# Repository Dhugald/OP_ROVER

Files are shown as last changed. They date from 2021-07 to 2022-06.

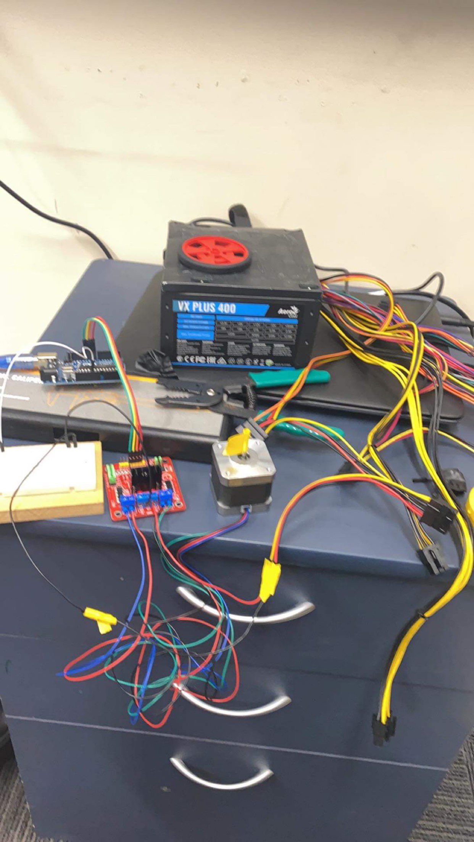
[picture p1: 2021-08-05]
Photos/StepperTest.jpg

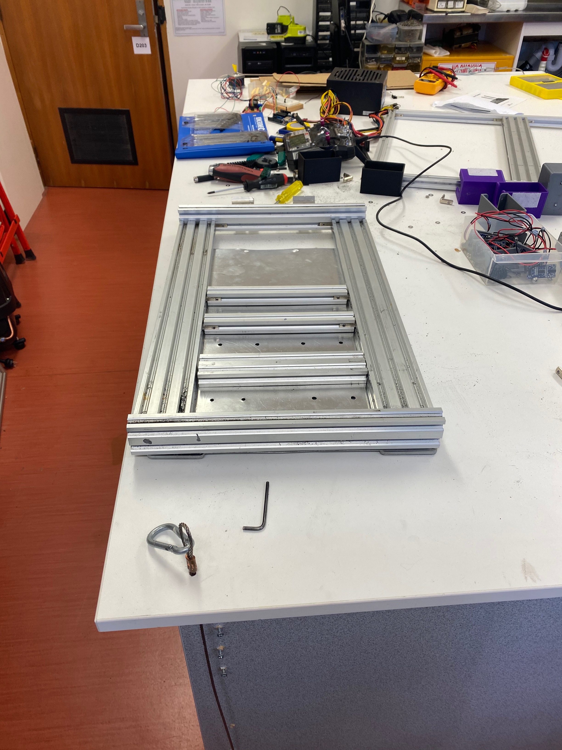
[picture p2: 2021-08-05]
Photos/Base.png

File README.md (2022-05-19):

# Rover Project

## This is the main github for the Rover project.
The purpose of this project is to create a self driving all terrain surverying robot, Used for checking out areas that could be unsafe for people to get to.

We want to be able to have it get over and around hazardous areas autonomously and map out areas using a lidar to show any risks and areas of concern.

# Members
- Reuben Watt
- Taylor Medder
- Dhugald Spry

# Plan
## Base plan

Rover has a 540mm x 320mm base.
Need to trim off the sides of the existing frame, maybe create a smaller box frame for the internal components?

## Wheels and legs planning
750mm length for the rocker-bogie when set-up, need to calculate the total length of parts
150mm diameter wheels (Similar to the ones used to farmbot(killbot) if possible to find).

Might need to make a 3d model of the base and the legs to get a better feel of them.

## Sensor layout
- Lidar to make a minimap to find entrys and exits.
- Lidar to spin and map a room in 3d on unity
- Camera to view through
- Sensors on all 4 sides to help with obstacle avoidance and detection

As a group we need to work out a sensor layout that we all agree on.

# Research links

Nvidia Jetson? Possible replacement for the Raspberry Pi, Could be cool to try
https://www.nvidia.com/en-us/autonomous-machines/jetson-store/

ROS with Lidar
https://www.generationrobots.com/blog/en/lidar-integration-with-ros-quickstart-guide-and-projects-ideas/
https://www.daslhub.org/unlv/wiki/doku.php?id=using_ros_to_read_data_from_a_hokuyo_scanning_laser_rangefinder

ROS Tutorial:
http://wiki.ros.org/ROS/Tutorials

Information on stepper motors:
https://nz.rs-online.com/web/generalDisplay.html?id=ideas-and-advice/stepper-motors-guide

NASA software:
https://software.nasa.gov/

Open Source Scaled Down 6 wheeled rover:
https://github.com/nasa-jpl/open-source-rover

CAD Parts for it: 
https://github.com/nasa-jpl/open-source-rover/tree/master/mechanical/rocker_bogie

Lidar 3D scan:
https://www.youtube.com/watch?v=gCpCGkwwy8I&ab_channel=TechsOnTube

Curiosity Rover 3D model and part descriptions:
https://mars.nasa.gov/msl/rover-3d/

Some More Images for ideas on the differential bar and rocker bogie system:
https://beatty-robotics.com/curiosity-mars-rover/

Lidar object detection:
https://www.youtube.com/watch?v=_--8K1BW_O4&t=2s&ab_channel=GreatScott%21

Some More Lidar Info For 3d Scan
http://charleslabs.fr/en/project-3D+Lidar+Scanner

Stepper motors:
https://www.youtube.com/watch?v=bkqoKWP4Oy4&ab_channel=GreatScott%21
https://www.youtube.com/watch?v=fHAO7SW-SZI&ab_channel=iforce2d

ROS tutorial:
https://www.youtube.com/watch?v=9U6GDonGFHw&ab_channel=JustinHuang

ROS lectures:
7 videos total From what I've seen will be really helpful.
https://www.youtube.com/playlist?list=PLE-BQwvVGf8HOvwXPgtDfWoxd4Cc6ghiP

Using a lidar for robot nav:
https://www.youtube.com/watch?v=OJNNm6iMOKk&ab_channel=TheLinuxFoundation

# Similar Projects

Uses Ardupilot and ROS, Contains alot of information and ideas that we can use:
https://dronebotworkshop.com/6-wheel-rover-introduction/

6 Wheeled Mars rover design for terrain traversing, equipment servicing, astronaut assistance and on-board testing.
More detailed and hightech than what we are going for but still contains information that might be usefull:
https://www.researchgate.net/publication/313543991_6_Wheeled_Mars_rover_design_for_terrain_traversing_equipment_servicing_astronaut_assistance_and_on-board_testing

A replica of the Perseverance rover, includes code and other helpful hints in the guide:
https://www.youtube.com/watch?v=NOZZMsMAGh0&ab_channel=HowToMechatronics
https://howtomechatronics.com/projects/diy-mars-perseverance-rover-replica-with-arduino/

ROS rover project, might have some useful information on the OS:
https://github.com/danielsnider/ros-rover

Example of what ROS can do, Ardupilot used to set a path:
https://www.youtube.com/watch?v=tqVH4lWk51Y&ab_channel=RandyMackay

Really useful robot, uses ROS:
https://youtu.be/M9ABtlEM788

# 3D printed parts list

Wheels (Need to be edited for casting):

# Shopping List
(Possible Stepper Motors from JayCar https://www.jaycar.co.nz/arduino-compatible-5v-stepper-motor-with-controller/p/XC4458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 - Have a feeling these will be to small for the work load.)

Wheels, the same ones from farmbot:
https://shop.wheelco.co.nz/shop//Wheels/Rubber+Wheels/Zero+Pressure+Wheel+150mm+-+Offset+Hub+-+ZPM150B.html

Possible stepper motors, might change type of motors.
https://www.digikey.co.nz/product-detail/en/trinamic-motion-control-gmbh/QSH6018-56-28-165/1460-1082-ND/4843432
https://www.digikey.co.nz/product-detail/en/trinamic-motion-control-gmbh/QSH6018-56-28-165/1460-1082-ND/4843433

Coupler for wheel and wheel motor 
https://www.jaycar.co.nz/solid-shaft-couplers-female-type-ii/p/YG2602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

Slipring
https://core-electronics.com.au/slip-ring-with-flange-22mm-diameter-6-wires-max-240v-at-2a.html

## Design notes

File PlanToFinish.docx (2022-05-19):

Wiring diagrams

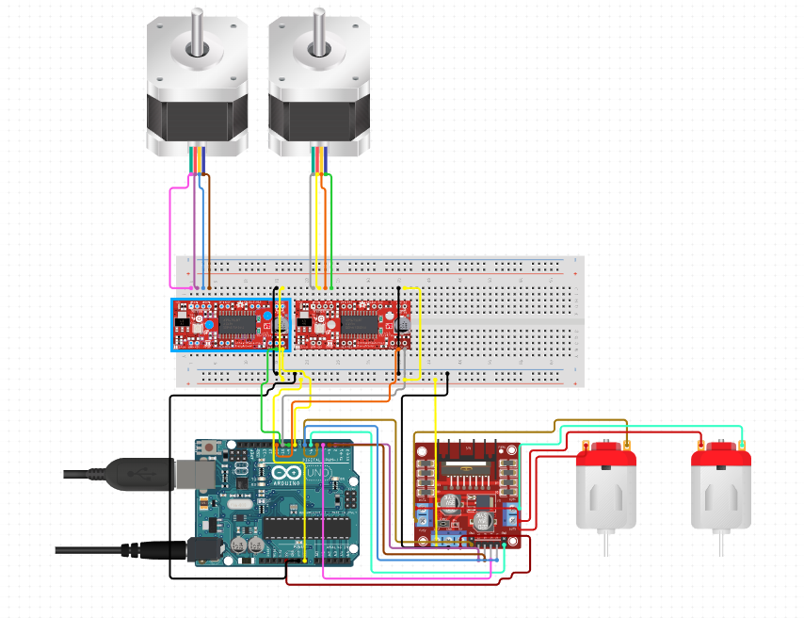
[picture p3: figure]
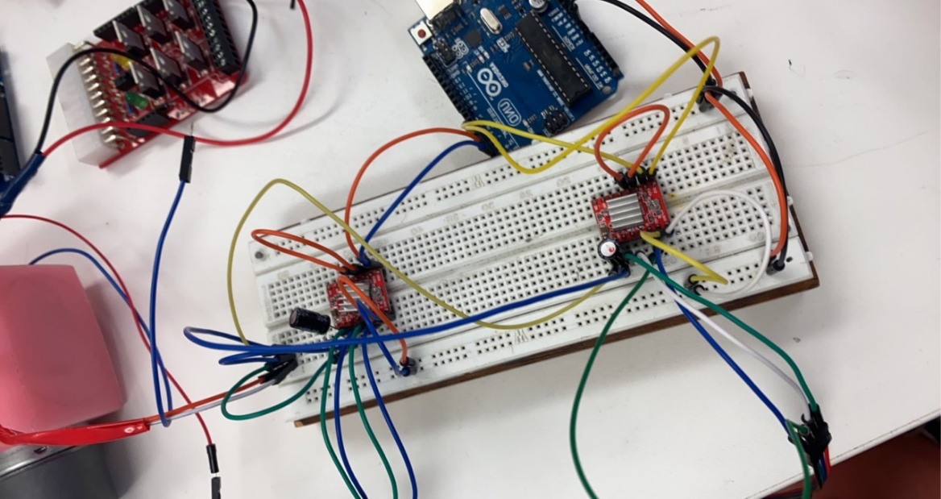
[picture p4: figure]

2x Slave board for the front and back motor set. Drivers are slightly different, but wiring is easy. External power for all the Arduinos and motor drivers from the PSU (hopefully) using the spark fun shield driver kit

Powering each Arduino using the 12v connector and the stepper drivers using the 5v

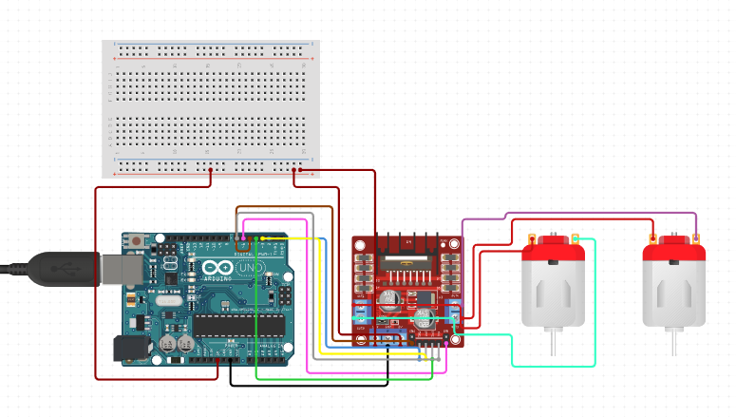
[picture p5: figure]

Slave board for the middle motors, very basic setup, can also use a TB6612FNG driver if it provides enough power to the motors.

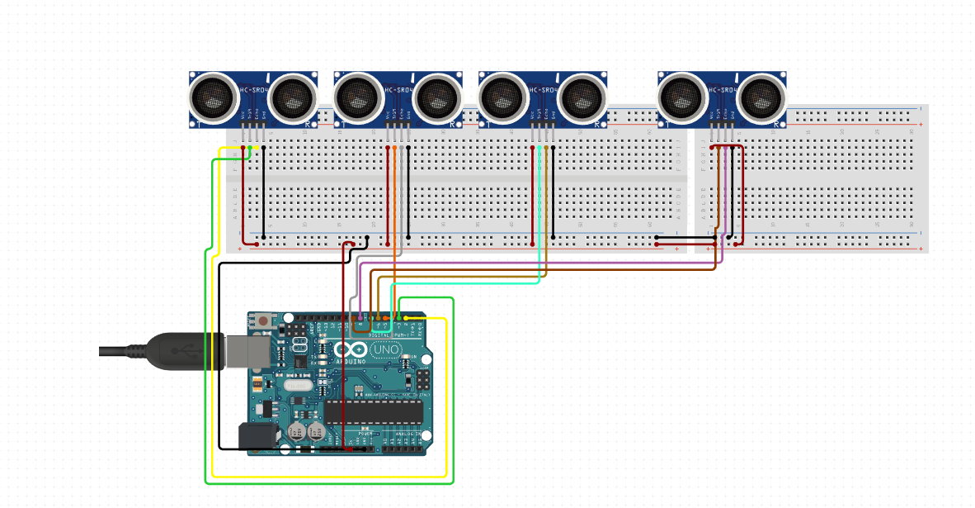
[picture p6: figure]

Master board includes the echo sensors to judge distances for decision making.

All the slave boards connect to the master board using i2c using the SDA and SCL ports on the uno (A4, A5)

The master board will be making the decisions based off the echo sensors then telling the slave boards the decision, Finite-state machine is probably the play for this.

All going the plan we will have a rover that can control itself and avoid obstacles.

Tasks that we need to complete.

- Mount the parts
  - Find bolts to connect our 3d prints to the rover.
  - Figure out most effective way to mount wheels to the DC motors.
- Wire up the motors
  - Either solder the parts or use breadboards
- Write code
  - Two slave boards will have the same code
  - Master board must do the decision making
  - Final slave board to power middle wheel motors
- Figure out the shield driver kit for the power distribution.
- Have fun doing it 😊 (optional)

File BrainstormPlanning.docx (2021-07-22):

Planning

1. 3D Mapping
  1. Detailed?
  2. Display dots in unity
2. 2D Mini-map
  1. Way pointing
3. Camera control
  1. Live feed
  2. Joystick
  3. Zoom in controls
  4. Capture live videos and photos
4. AI Risk evaluation
5. Wheel control
  1. 90° degree wheel rotation
  2. Rocker-bogie mechanism
6. Self Driving
  1. Sensor control
  2. Pathfinding
  3. Decision making
  4. Drive to waypoints from 2D map
7. Control buttons
  1. Start / stop
  2. Scan
  3. Photo?
  4. Video?

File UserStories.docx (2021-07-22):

User Stories

As a user I want to be able to remotely get a map of an area to spot potential areas of concern so that we aren’t putting people in possible harm’s way.

As a user I want to be able to see an area through the camera to spot risks in higher detail with control of the camera, so that we can have high detail photos and video of the potential risk area.

As a user I want the rover to safely navigate through areas of interest so that the rover doesn’t get any damage from the terrain.

As a creator I want to be able to build it in parts that will last, this will hopefully be done with help from the engineering students so that the parts are built to last and won’t have to be replaced as often.

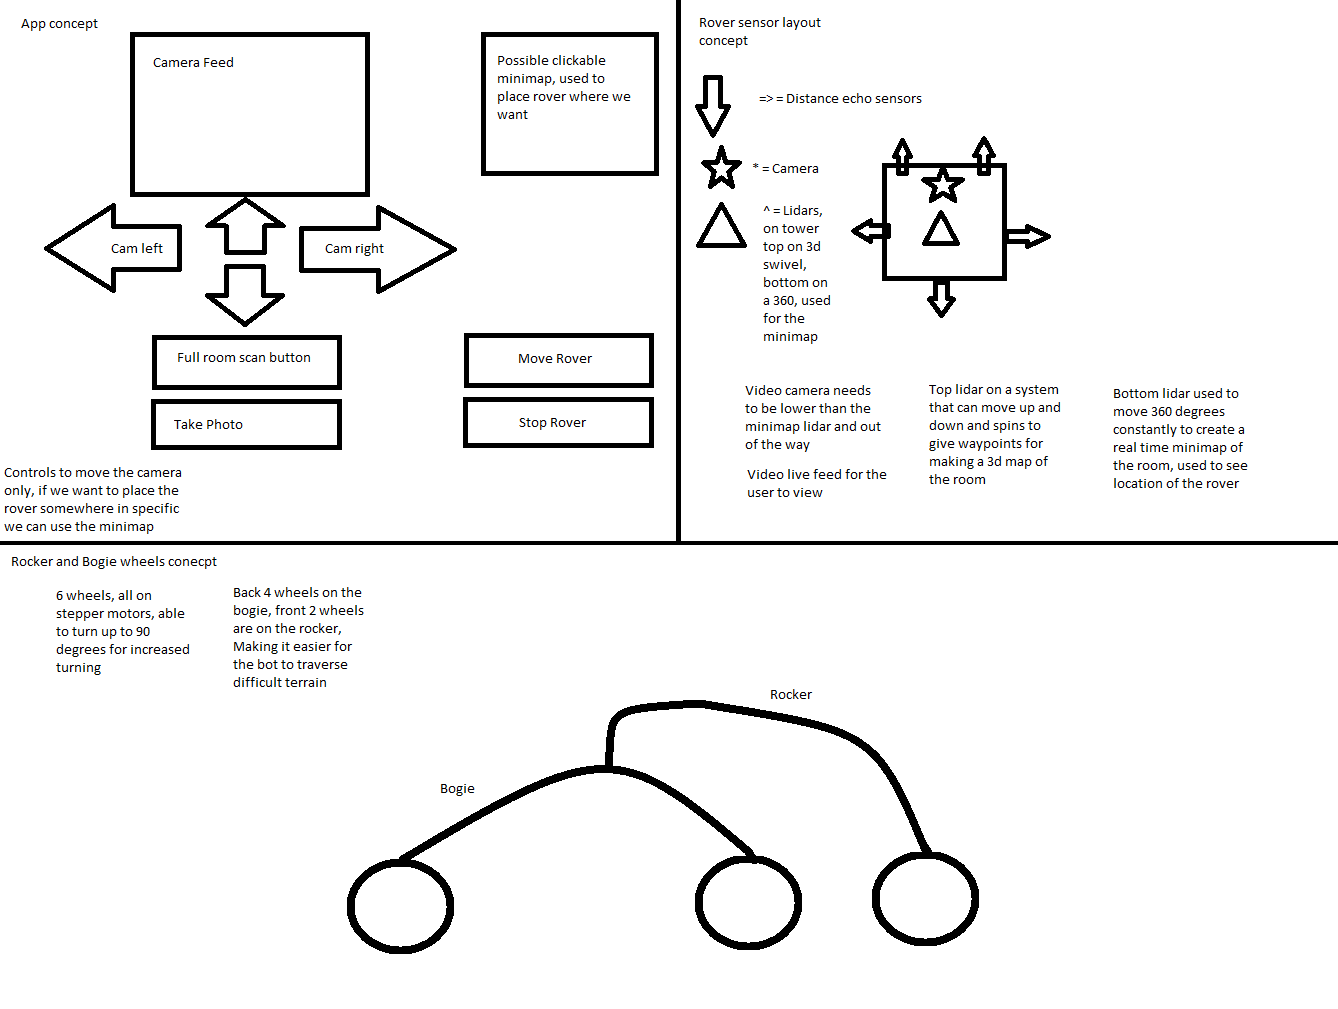
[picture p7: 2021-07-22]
Photos/Concepts.png

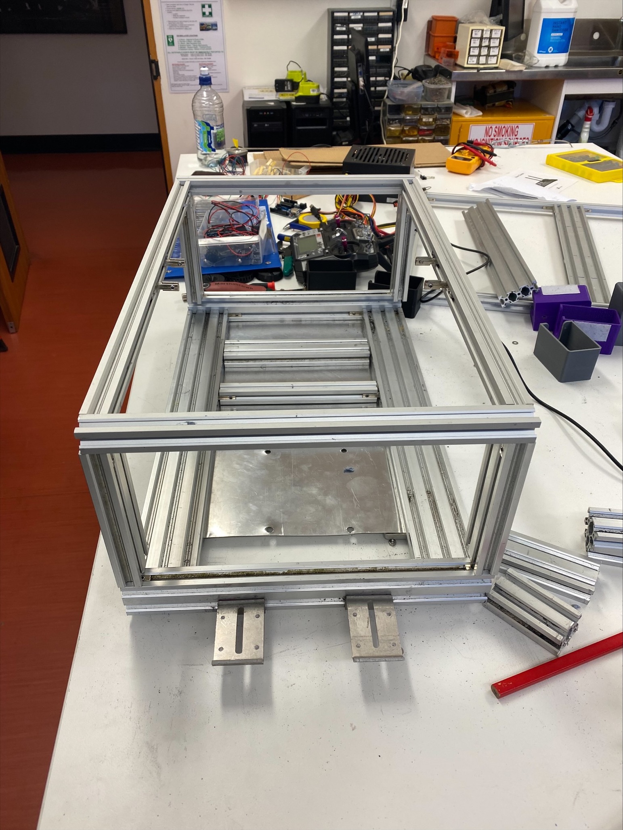
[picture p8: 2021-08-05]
Photos/Frame.png

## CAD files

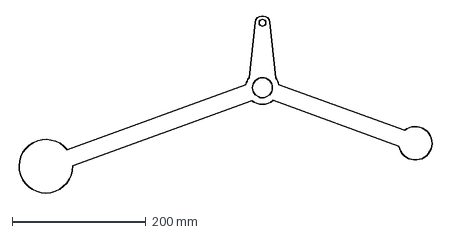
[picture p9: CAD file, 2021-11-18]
3D parts/DXF Files/Rocker.dxf
623.7 x 267.2 mm

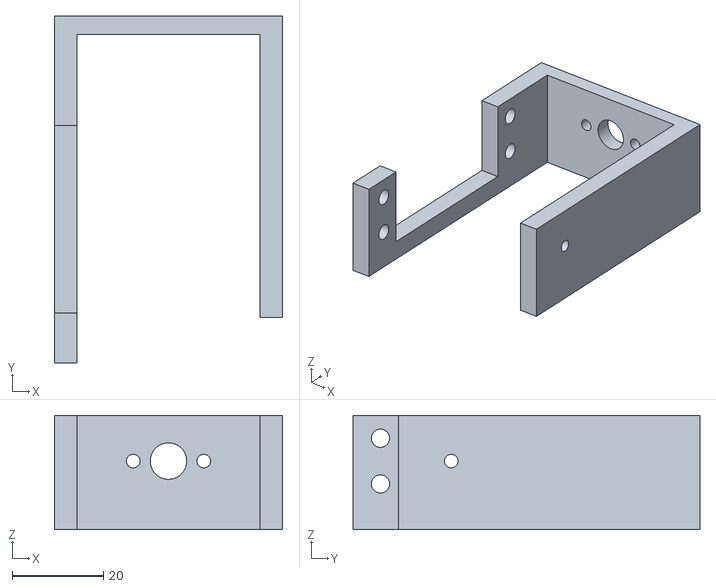
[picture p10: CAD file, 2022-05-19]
3D parts/Lidar Scanner Brackets/Redesigned LIDAR-Servo-Housing-Pocket.stl
50.0 x 76.0 x 25.0

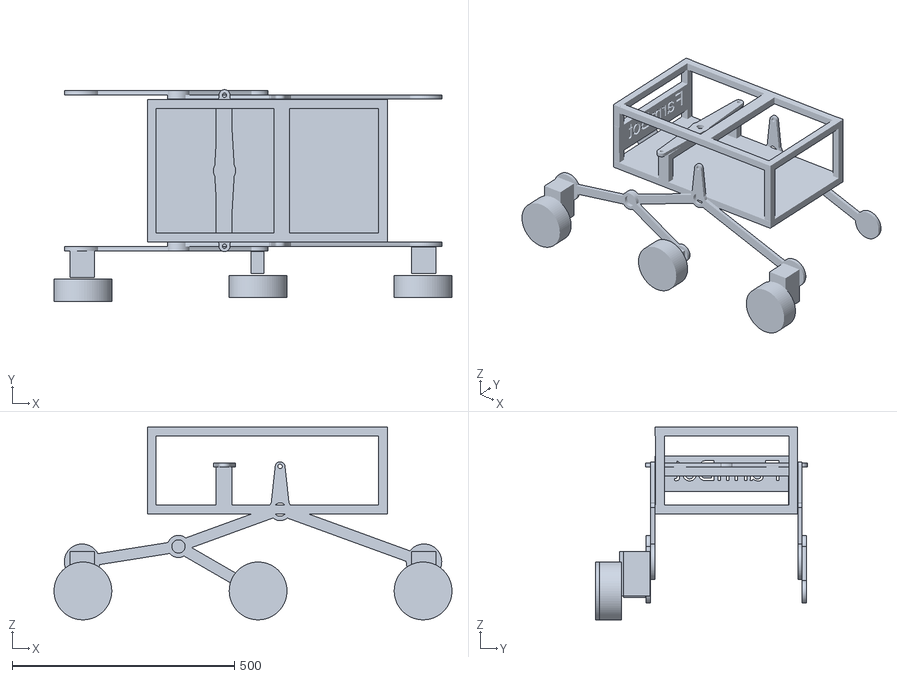
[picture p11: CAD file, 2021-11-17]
3D parts/Rover Bogie Rocker v14 (NEW).stl
895.0 x 476.1 x 433.1

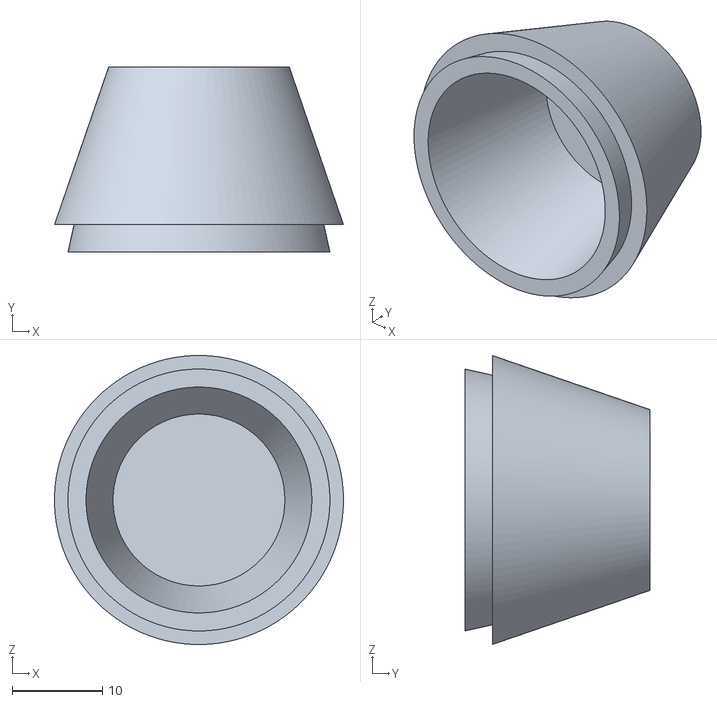
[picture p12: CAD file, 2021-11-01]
3D parts/Wheel/hub cap v1.stl
32.0 x 20.5 x 32.0

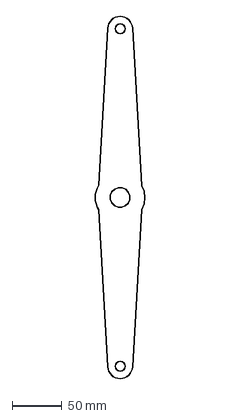
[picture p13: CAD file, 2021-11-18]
3D parts/DXF Files/Differential Bar.dxf
52.1 x 364.6 mm

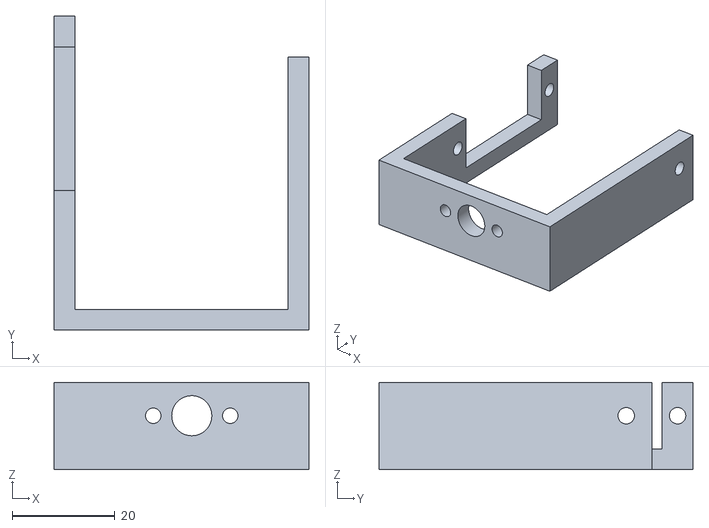
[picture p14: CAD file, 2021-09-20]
3D parts/Lidar Scanner Brackets/LIDAR-Servo-Housing-Pocket002.stl
49.6 x 61.1 x 17.0

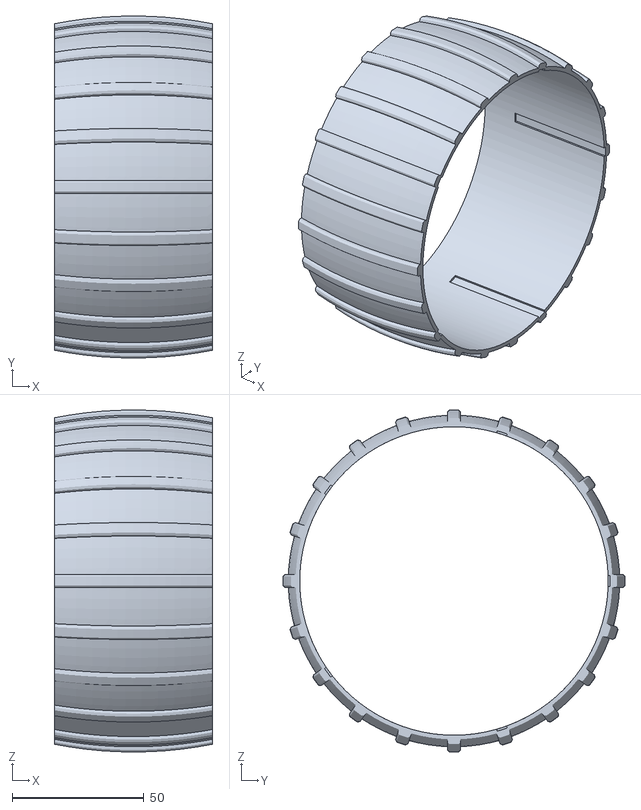
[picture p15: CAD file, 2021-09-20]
3D parts/Wheel/wheel_rim_2.stl
60.0 x 129.6 x 129.6

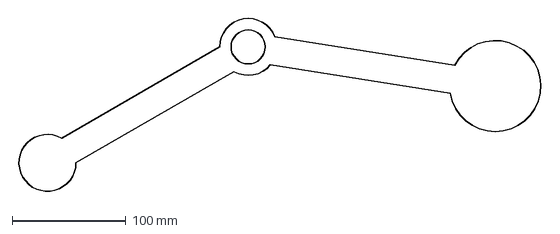
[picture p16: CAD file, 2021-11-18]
3D parts/DXF Files/Bogie.dxf
463.1 x 155.7 mm

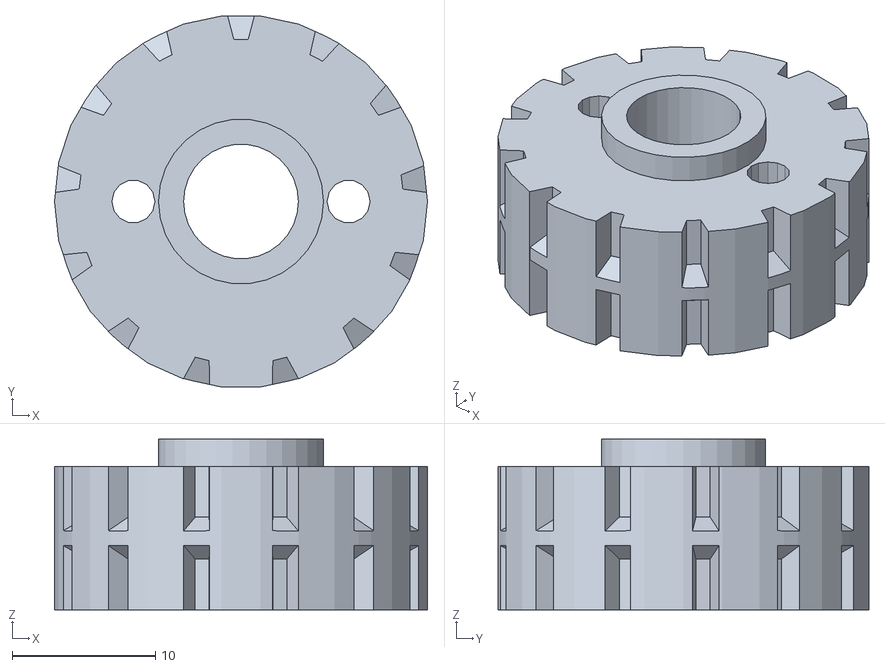
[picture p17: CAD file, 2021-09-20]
3D parts/Lidar Scanner Brackets/Slipring.stl
26.0 x 25.9 x 11.9

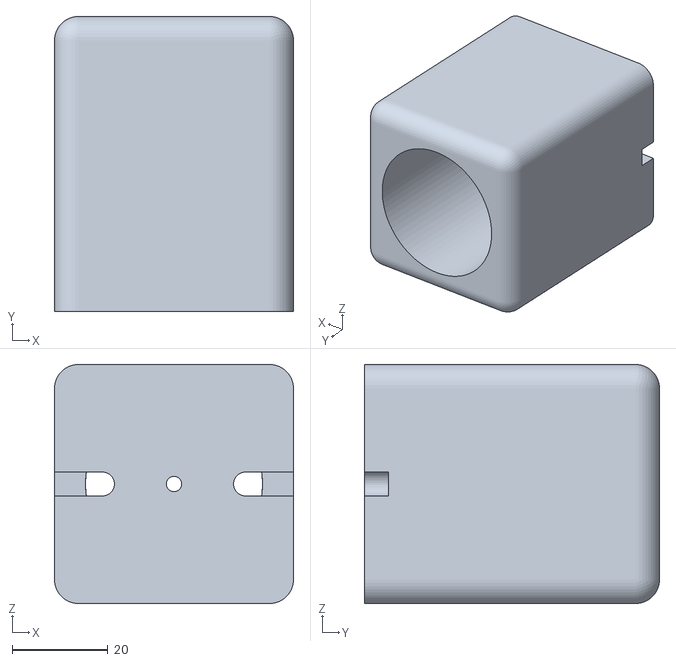
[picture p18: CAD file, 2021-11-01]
3D parts/Middle Ankle Joint v2.stl
50.0 x 61.7 x 50.0

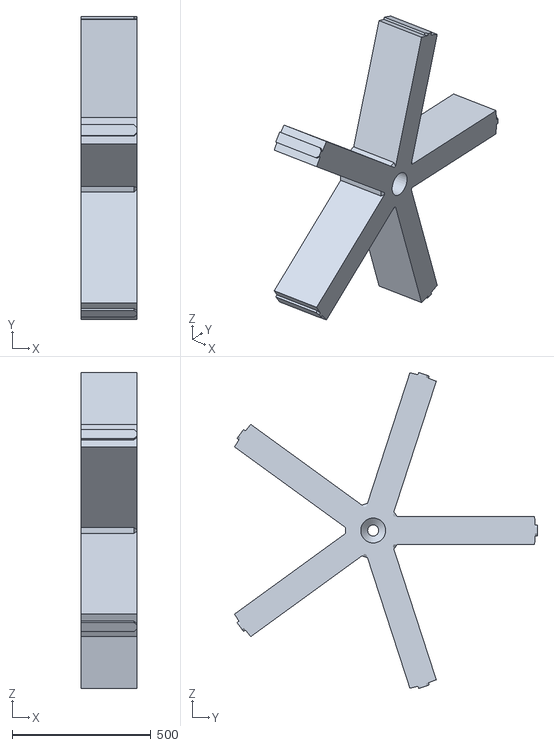
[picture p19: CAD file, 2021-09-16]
3D parts/Wheel/wheel_hub_thick_spokes.stl
200.0 x 1092.1 x 1138.6

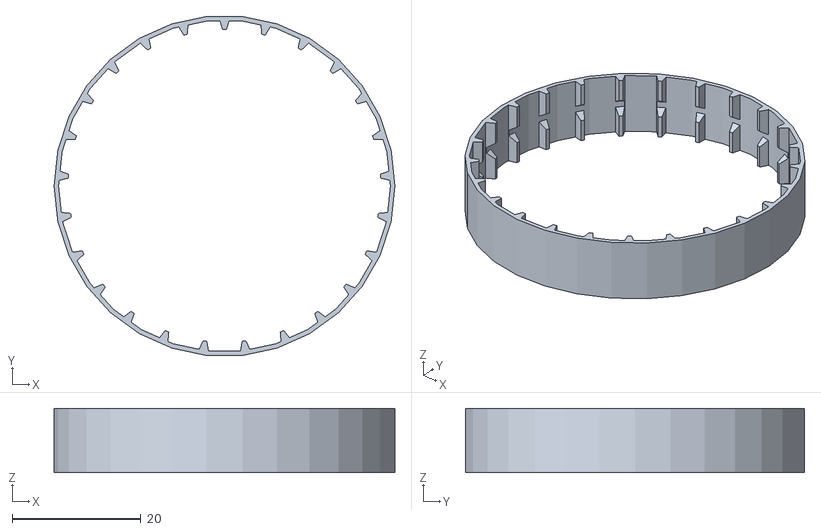
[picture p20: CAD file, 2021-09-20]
3D parts/Lidar Scanner Brackets/AnyConv.com__DriveBelt.stl
52.9 x 52.6 x 10.0

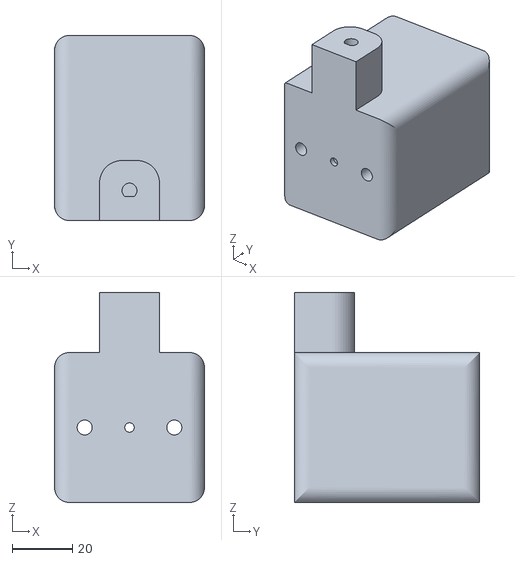
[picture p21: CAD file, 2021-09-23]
3D parts/Bigger Ankle Joint v1.stl
50.0 x 61.7 x 70.0

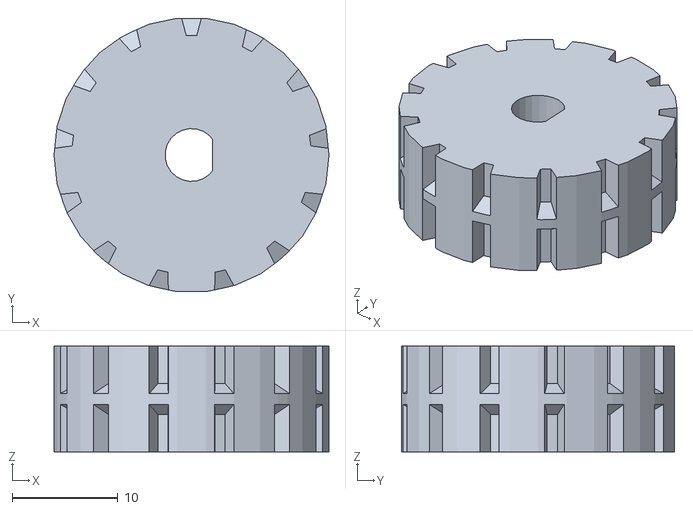
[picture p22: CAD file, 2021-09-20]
3D parts/Lidar Scanner Brackets/Motor.stl
26.0 x 25.9 x 10.0

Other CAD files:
3D parts/Lidar Scanner Brackets/LIDAR-Mount-Pocket.stl
3D parts/Rover Bogie Rocker v7.stl
3D parts/Lidar Scanner Brackets/LIDAR-Sensor-Chamfer001.stl
3D parts/Stepper_Holder v3.stl
3D parts/Hole Plug (For Bolt) v3.stl
3D parts/Rover_Ankle Joint v2.stl
3D parts/Shoulder_Screw_spacer.stl

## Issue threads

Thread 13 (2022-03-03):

Mount 3d printed parts to the rover, print any parts that aren't already complete.

Dhugald, 2022-03-03:

Dhugald, 2022-03-03:
Print the pieces for the Lidar sensor

Dhugald, 2022-03-03:
Print the final brackets needed for the rover body.

Dhugald, 2022-03-03:
Clean up and mount the current 3D printed sections.

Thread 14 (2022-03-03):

Research parts, figure out motors, main board, how we want to control the sensors wirelessly.

Dhugald, 2022-03-03:

Dhugald, 2022-03-03:
Figure out a way to power and use all the motors at one time

Dhugald, 2022-03-03:
Find a way to monitor the sensors wirelessly, see [here](https://dronebotworkshop.com/6-wheel-rover-introduction/) for ideas?

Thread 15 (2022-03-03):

Find a way of wiring the rover up in a way that is efficient and effective.

Dhugald, 2022-03-03:

Dhugald, 2022-03-03:
See [Testing issue](https://github.com/Dhugald/OP_ROVER/issues/16)

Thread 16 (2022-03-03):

Test as we go, make sure any fixes we do to parts doesn't effect how the other components work.

Dhugald, 2022-03-03:

Dhugald, 2022-03-03:
Stress test the parts on the rover without anything mounted.

Dhugald, 2022-03-03:
Simulate the wiring using [partsim](https://www.partsim.com/simulator)

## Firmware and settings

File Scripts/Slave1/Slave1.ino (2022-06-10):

// slave for the front wheel set of the rover
#include <Arduino.h>
#include <Wire.h>
#include <DCMDriverL298.h>

#define SLAVE 10 //Front Wheel set
#define ANSWER 10 // size of the answer
// Pin Definitions
#define DCMOTORDRIVERL298_PIN_INT1	2
#define DCMOTORDRIVERL298_PIN_ENB	6
#define DCMOTORDRIVERL298_PIN_INT2	3
#define DCMOTORDRIVERL298_PIN_ENA	5
#define DCMOTORDRIVERL298_PIN_INT3	4
#define DCMOTORDRIVERL298_PIN_INT4	7

DCMDriverL298 dcMotorDriverL298 = DCMDriverL298(DCMOTORDRIVERL298_PIN_INT1, DCMOTORDRIVERL298_PIN_ENB, DCMOTORDRIVERL298_PIN_INT2, DCMOTORDRIVERL298_PIN_ENA, DCMOTORDRIVERL298_PIN_INT3, DCMOTORDRIVERL298_PIN_INT4);

//Stepper motor pins
const int stepPin1 = 8; 
const int dirPin1 = 9;
const int stepPin2 = 10;
const int dirPin2 = 11;


void setup() {
  Serial.begin(9600);
  Wire.begin(SLAVE);
  //receive the message from the master and use it to get the state of the rover
  Wire.onReceive(receiveEvent);
  pinMode(stepPin1, OUTPUT);
  pinMode(dirPin1, OUTPUT);
  pinMode(stepPin2, OUTPUT);
  pinMode(dirPin2, OUTPUT);
}

// function to get the state of the rover from the master using i2c communication
void receiveEvent() {
  Wire.available();
  int state = Wire.read();
  Serial.println(state);
  switch(state){
    case 0:
      Serial.println("FORWARD");
      Forward();
      break;
    case 1:
      Serial.println("LEFT");
      Left();
      break;
    case 2: 
      Serial.println("RIGHT");
      Right();
      break;
    case 3: 
      Serial.println("BACK");
      Back();
      break;
    case 4: 
      Serial.println("BACKLEFT");
      BackLeft();
      break;
    case 5: 
      Serial.println("BACKRIGHT");
      BackRight();
      break;
    case 6: 
      Serial.println("FORWARDLEFT");
      ForwardLeft();
      break;
    case 7: 
      Serial.println("FORWARDRIGHT");
      ForwardRight();
      break;
    case 8:
      Serial.println("STOP");
      Stop();
      break;
    default:  
      Serial.println("ERROR");
      Stop();
      break;
  }
}
//Forward powers the DC motors to move the rover forward, Stepper motors are stationary 
void Forward(){
  digitalWrite(stepPin1, LOW);
  digitalWrite(stepPin2, LOW);
  digitalWrite(dirPin1, LOW);
  digitalWrite(dirPin2, LOW);
  dcMotorDriverL298.setMotorA(100,1);
  dcMotorDriverL298.setMotorB(100,1);
  
}

void Left(){
  //rotate the steppers 90 degrees to the left and drive the rover forward
  digitalWrite(stepPin1, HIGH);
  digitalWrite(stepPin2, HIGH);
  digitalWrite(dirPin1, LOW);
  digitalWrite(dirPin2, LOW);
  dcMotorDriverL298.setMotorA(100,1);
  dcMotorDriverL298.setMotorB(100,1);
  //rotate the steppers back to the original position
  digityalWrite(stepPin1, LOW);
  digitalWrite(stepPin2, LOW);
  digitalWrite(dirPin1, LOW);
  digitalWrite(dirPin2, LOW);


}

void Right(){
  //rotate the steppers 90 degrees to the right and drive the rover forward
  digitalWrite(stepPin1, LOW);
  digitalWrite(stepPin2, LOW);
  digitalWrite(dirPin1, HIGH);
  digitalWrite(dirPin2, HIGH);
  dcMotorDriverL298.setMotorA(100,1);
  dcMotorDriverL298.setMotorB(100,1);
  //rotate the steppers back to the original position
  digitalWrite(stepPin1, LOW);
  digitalWrite(stepPin2, LOW);
  digitalWrite(dirPin1, LOW);
  digitalWrite(dirPin2, LOW);


}

void Back(){
  //drive the DC motors backward and stop the steppers
  digitalWrite(stepPin1, LOW);
  digitalWrite(stepPin2, LOW);
  digitalWrite(dirPin1, LOW);
  digitalWrite(dirPin2, LOW);
  dcMotorDriverL298.setMotorA(100,0);
  dcMotorDriverL298.setMotorB(100,0);


}

void BackLeft(){
  //reverse the DC motors and rotate the steppers 90 degrees to the left
  digitalWrite(stepPin1, HIGH);
  digitalWrite(stepPin2, HIGH);
  digitalWrite(dirPin1, LOW);
  digitalWrite(dirPin2, LOW);
  dcMotorDriverL298.setMotorA(100,0);
  dcMotorDriverL298.setMotorB(100,0);
  //rotate the steppers back to the original position
  digitalWrite(stepPin1, LOW);
  digitalWrite(stepPin2, LOW);
  digitalWrite(dirPin1, LOW);
  digitalWrite(dirPin2, LOW);

}

void BackRight(){
  //reverse the DC motors and rotate the steppers 90 degrees to the right
  digitalWrite(stepPin1, HIGH);
  digitalWrite(stepPin2, HIGH);
  digitalWrite(dirPin1, HIGH);
  digitalWrite(dirPin2, HIGH);

  dcMotorDriverL298.setMotorA(100,0);
  dcMotorDriverL298.setMotorB(100,0);

  //rotate the steppers back to the original position
  digitalWrite(stepPin1, LOW);
  digitalWrite(stepPin2, LOW);
  digitalWrite(dirPin1, LOW);
  digitalWrite(dirPin2, LOW);
}

void ForwardLeft(){
  //turn the motors 90 degrees to the left and drive the rover forward
  digitalWrite(stepPin1, LOW);
  digitalWrite(stepPin2, LOW);
  digitalWrite(dirPin1, LOW);
  digitalWrite(dirPin2, LOW);
  dcMotorDriverL298.setMotorA(100,1);
  dcMotorDriverL298.setMotorB(100,1);
  //Rotate the steppers back to their original position
  digitalWrite(stepPin1, HIGH);
  digitalWrite(stepPin2, HIGH);
  digitalWrite(dirPin1, HIGH);
  digitalWrite(dirPin2, HIGH);


}

void ForwardRight(){
  //turn the motors 90 degrees to the right and drive the rover forward
  digitalWrite(stepPin1, LOW);
  digitalWrite(stepPin2, LOW);
  digitalWrite(dirPin1, LOW);
  digitalWrite(dirPin2, LOW);
  dcMotorDriverL298.setMotorA(100,1);
  dcMotorDriverL298.setMotorB(100,1);
  //Rotate the steppers back to their original position
  digitalWrite(stepPin1, HIGH);
  digitalWrite(stepPin2, HIGH);
  digitalWrite(dirPin1, HIGH);
  digitalWrite(dirPin2, HIGH);
}

void Stop(){
  dcMotorDriverL298.stopMotors();
  digitalWrite(stepPin1, LOW);
  digitalWrite(stepPin2, LOW);
  digitalWrite(dirPin1, LOW);
  digitalWrite(dirPin2, LOW);
}

void loop() {
  delay(50);
}

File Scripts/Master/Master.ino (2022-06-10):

/*
  The master controller for the rover project.
  uses 4 echo sensors to detect obstacles to all sides of the rover.
  finite state machine to control rover using the information from the sensors.
*/


#include <Arduino.h>
#include <Servo.h>
#include <Wire.h>
#include <NewPing.h>

#define sensor1trig  3 //Front trigger
#define sensor1echo  2 //Front echo
#define sensor2trig  5 //Left
#define sensor2echo  4 //Left
#define sensor3trig  7 //Right
#define sensor3echo  6 //Right
#define sensor4trig  9 //Back
#define sensor4echo  8 //Back


#define SLAVE1 10 //Front Wheel set
#define SLAVE2 11 //Middle Wheel set
#define SLAVE3 12 //Back Wheel set

#define ANSWER 10 // size of the answer


NewPing sensor1(sensor1trig, sensor1echo);
NewPing sensor2(sensor2trig, sensor2echo);
NewPing sensor3(sensor3trig, sensor3echo);
NewPing sensor4(sensor4trig, sensor4echo);
enum states {
    FORWARD,
    LEFT,
    RIGHT,
    BACK,
    STOP,
    BACKLEFT,
    BACKRIGHT,
    FORWARDLEFT,
    FORWARDRIGHT,
  };
states state; 
void setup()
{
  Serial.begin(9600);
  Wire.begin();

}
void loop() {
  getState();
  delay(50);
}
//function to return the state of the rover
void getState() {
  int sensor1dist = sensor1.ping_cm();
  int sensor2dist = sensor2.ping_cm();
  int sensor3dist = sensor3.ping_cm();
  int sensor4dist = sensor4.ping_cm();
  Serial.println(sensor1dist);
  Serial.println(sensor2dist);
  Serial.println(sensor3dist);
  Serial.println(sensor4dist);
  
  if (sensor1dist < 15 && sensor2dist > 15 && sensor3dist > 15 && sensor4dist > 15) {
    state = BACK;
  }
  else if (sensor2dist < 15 && sensor3dist > 15 && sensor4dist > 15 && sensor1dist > 15) {
    state = RIGHT;
  }
  else if (sensor3dist < 15 && sensor4dist > 15 && sensor1dist > 15 && sensor2dist > 15) {
    state = LEFT;
  }
  else if (sensor4dist < 15 && sensor1dist > 15 && sensor2dist > 15 && sensor3dist > 15) {
    state = FORWARD;
  }
  else if (sensor1dist < 15 && sensor2dist < 15 && sensor3dist > 15 && sensor4dist > 15) {
    state = BACKLEFT;
  }
  else if (sensor1dist < 15 && sensor3dist < 15 && sensor2dist > 15 && sensor4dist > 15) {
    state = BACKRIGHT;
  }
  else if (sensor4dist < 15 && sensor2dist < 15 && sensor3dist > 15 && sensor1dist > 15) {
    state = FORWARDLEFT;
  }
  else if (sensor4dist < 15 && sensor3dist < 15 && sensor2dist > 15 && sensor1dist > 15) {
    state = FORWARDRIGHT;
  }
  else if (sensor1dist > 15 && sensor2dist > 15 && sensor3dist > 15 && sensor4dist > 15) {
    state = STOP;
  }
  
  else {
    state = FORWARD;
  }
  sendState(state);
  //delay(2500);
}
//function to send the state to the slavess
static sendState(states st) {
  switch (st) {
    case FORWARD:
      Wire.beginTransmission(SLAVE1);
      Wire.write(0);
      Wire.endTransmission();
      // Wire.beginTransmission(SLAVE2);
      // Wire.write(0);
      // Wire.endTransmission();
      // Wire.beginTransmission(SLAVE3);
      // Wire.write(0);
      // Wire.endTransmission();
      break;
    case LEFT:
      Wire.beginTransmission(SLAVE1);
      Wire.write(1);
      Wire.endTransmission();
      // Wire.beginTransmission(SLAVE2);
      // Wire.write(1);
      // Wire.endTransmission();
      // Wire.beginTransmission(SLAVE3);
      // Wire.write(1);
      // Wire.endTransmission();
      break;
    case RIGHT:
      Wire.beginTransmission(SLAVE1);
      Wire.write(2);
      Wire.endTransmission();
      // Wire.beginTransmission(SLAVE2);
      // Wire.write(2);
      // Wire.endTransmission();
      // Wire.beginTransmission(SLAVE3);
      // Wire.write(2);
      // Wire.endTransmission();
      break;
    case BACK:
      Wire.beginTransmission(SLAVE1);
      Wire.write(3);
      Wire.endTransmission();
      // Wire.beginTransmission(SLAVE2);
      // Wire.write(3);
      // Wire.endTransmission();
      // Wire.beginTransmission(SLAVE3);
      // Wire.write(3);
      // Wire.endTransmission();
      break;
    case BACKLEFT:
      Wire.beginTransmission(SLAVE1);
      Wire.write(4);
      Wire.endTransmission();
      // Wire.beginTransmission(SLAVE2);
      // Wire.write(4);
      // Wire.endTransmission();
      // Wire.beginTransmission(SLAVE3);
      // Wire.write(4);
      // Wire.endTransmission();
      break;
    case BACKRIGHT:
      Wire.beginTransmission(SLAVE1);
      Wire.write(5);
      Wire.endTransmission();
      // Wire.beginTransmission(SLAVE2);
      // Wire.write(5);
      // Wire.endTransmission();
      // Wire.beginTransmission(SLAVE3);
      // Wire.write(5);
      // Wire.endTransmission();
      break;
    case FORWARDLEFT:
      Wire.beginTransmission(SLAVE1);
      Wire.write(6);
      Wire.endTransmission();
      // Wire.beginTransmission(SLAVE2);
      // Wire.write(6);
      // Wire.endTransmission();
      // Wire.beginTransmission(SLAVE3);
      // Wire.write(6);
      // Wire.endTransmission();
      break;
    case FORWARDRIGHT:
      Wire.beginTransmission(SLAVE1);
      Wire.write(7);
      Wire.endTransmission();
      // Wire.beginTransmission(SLAVE2);
      // Wire.write(7);
      // Wire.endTransmission();
      // Wire.beginTransmission(SLAVE3);
      // Wire.write(7);
      // Wire.endTransmission();
      break;
    case STOP:
      Wire.beginTransmission(SLAVE1);
      Wire.write(8);
      Wire.endTransmission();
      // Wire.beginTransmission(SLAVE2);
      // Wire.write(8);
      // Wire.endTransmission();
      // Wire.beginTransmission(SLAVE3);
      // Wire.write(8);
      // Wire.endTransmission();
      break;
  }
}

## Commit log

2021-08-05 Deigned an ankle joint to connect the two motors in front 2 and back 2 wheels
    [Rover_Ankle Joint v1.stl]
2021-08-05 Added photos of the start to the base, frame and the testing of stepper motors
2021-08-09 reoriented ankle joint for printing
    [Rover_Ankle Joint v2.stl]
2021-08-11 Made a 3d model of something to hold the 4 stepper motors
    [Stepper_Holder v1.stl]
2021-08-11 refined stepper holder
    [Rover_Ankle Joint v1.stl, Stepper_Holder v1.stl, Stepper_Holder v2.stl]
2021-08-12 removed holes from stepper holder
    [Stepper_Holder v2.stl, Stepper_Holder v3.stl]
2021-09-16 Rover Rocker Bogie and General 3D Model
    [Rover Bogie Rocker v7.stl]
2021-09-20 Start of the app for the controlling of the cameras and outputing the data '
2021-09-20 Added 3D parts for Lidar Bracket and wheel
    [AnyConv.com__DriveBelt.stl, LIDAR-Mount-Pocket.stl, LIDAR-Sensor-Chamfer001.stl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]
2021-09-23 Added stl for a bigger ankle joint
    [Bigger Ankle Joint v1.stl]
2021-11-01 Added photos of the current state of the rover
    [test v0.stl]
2021-11-04 Plug To Fit a bolt
    [Hole Plug (For Bolt) v3.stl]
2021-11-17 Newer Version Of Rocker Bogie
    Since the last one is a bit out of date
    [Rover Bogie Rocker v14 (NEW).stl]
2021-11-17 added photos
    [Shoulder_Screw_spacer.stl]
2021-11-18 DXF Files Converions for Cutting out Rocker Bogie
    [Bogie.dxf, Differential Bar.dxf, Rocker.dxf]
2022-03-19 Added Link
    Added Link to more info on lidar 3d scan.
2022-04-05 Added The Redesigned Lidar/Servo Housing pocket
    Redesigned the housing to better fit the servo we are using.
    [Redesigned LIDAR-Servo-Housing-Pocket.stl]
2022-06-10 adding start of code for the master and slave boards
2022-06-23 lidar script
